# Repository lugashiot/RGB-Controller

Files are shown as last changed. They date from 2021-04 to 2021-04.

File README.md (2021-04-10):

# RGB-Controller
Repository for our selfmade RGB Controller.

We want to use different methods to use the Controller, eg. Blynk or MQTT.
Blynk is done already, but we are still working on MQTT.

Our project is for personal use only, you are not allowed to sell it in any kind.
If you want to build it yourself, check the [Hardware](/Hardware/) directory, all the parts are listed and you can upload the zip folder to order a PCB. 
We purchased the ESP8266 and the 12V PSU via Aliexpress. (The ESP usually has some headers included)
We used https://jlcpcb.com/ for the PCB and https://lcsc.com/ for the parts.

We used code of these repositories:
- https://github.com/tzapu/WiFiManager
- https://github.com/bblanchon/ArduinoJson
- https://github.com/jenscski/DoubleResetDetect
- https://github.com/esp8266/Arduino
- https://blynk.io/

#theoretisch genial, praktisch egal

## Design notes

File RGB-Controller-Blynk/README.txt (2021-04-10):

Final Version:
Über eigenen Wlan Hotspot konfigurieren
 - Authkey ändern
 - Pinkombination ändern (wenn RGB am Lichtstreifen anders angeordnet ist)
DEBUG auskommentieren wenn nicht benötigt
remotecontrol definieren um via http requests variablen zu verändern (zb Farbe, Helligkeit etc.)
RGBSLIDERCODE definieren um eigene RGB Werte am Lichtstreifen auszugeben (Slider müssen in der App extra hinzugefügt werden! Dreifarbige Werte werden am Lichtstreifen sehr weißlich dargestellt)

Um das Wlan zu konfigurieren, 2 mal schnell hintereinander den Reset Knopf drücken.
LED leuchtet jetzt durchgehend.
In der App den Authkey kopieren
mit Wlan "RGB-Controller" verbinden und auf "Im Netzwerk anmelden" klicken.
Jetzt auf "Configure Wifi" klicken,
Wlan Details eingeben
Authkey einfügen
(wenn nötig Pinkombination verändern)
und auf "Save" klicken.

Der RGB Controller ist jetzt fertig eingerichtet.

Virtual Pin Belegung:

V0: 	Menu (1,2,3,4) Farbmodi
V1: 	Delay (1-30) slider
V2: 	manual button (0,1) sliderbutton
V3,4,5: RGB Slider (0-255) 
V7: 	RGB ZEBRA (0-255)
V9: 	brightness slider (1-100)
V10: 	onoff (0,1)

NUR WENN remotecontrol DEFINIERT IST
V30,31,32: 	RGB Remote (0-255)

http://blynk-cloud.com/authkey/update/V(#PIN)?value=(#WERT)
http://blynk-cloud.com/authkey/get/V(#PIN)

Farben stimmen nicht überein? In Web Menü (siehe Wlan konfigurieren) bei "Pin Belegung (optional)" den richtigen Zahlencode für den Lichtstreifen einfügen.

Pin Header  +12V G R B
Colorcode        540      

Pin Header  +12V R G B
Colorcode        450

Pin Header  +12V B G R
Colorcode        054

Pin Header  +12V B R G
Colorcode        045

Pin Header  +12V G B R
Colorcode        504

Pin Header  +12V R B G
Colorcode        405

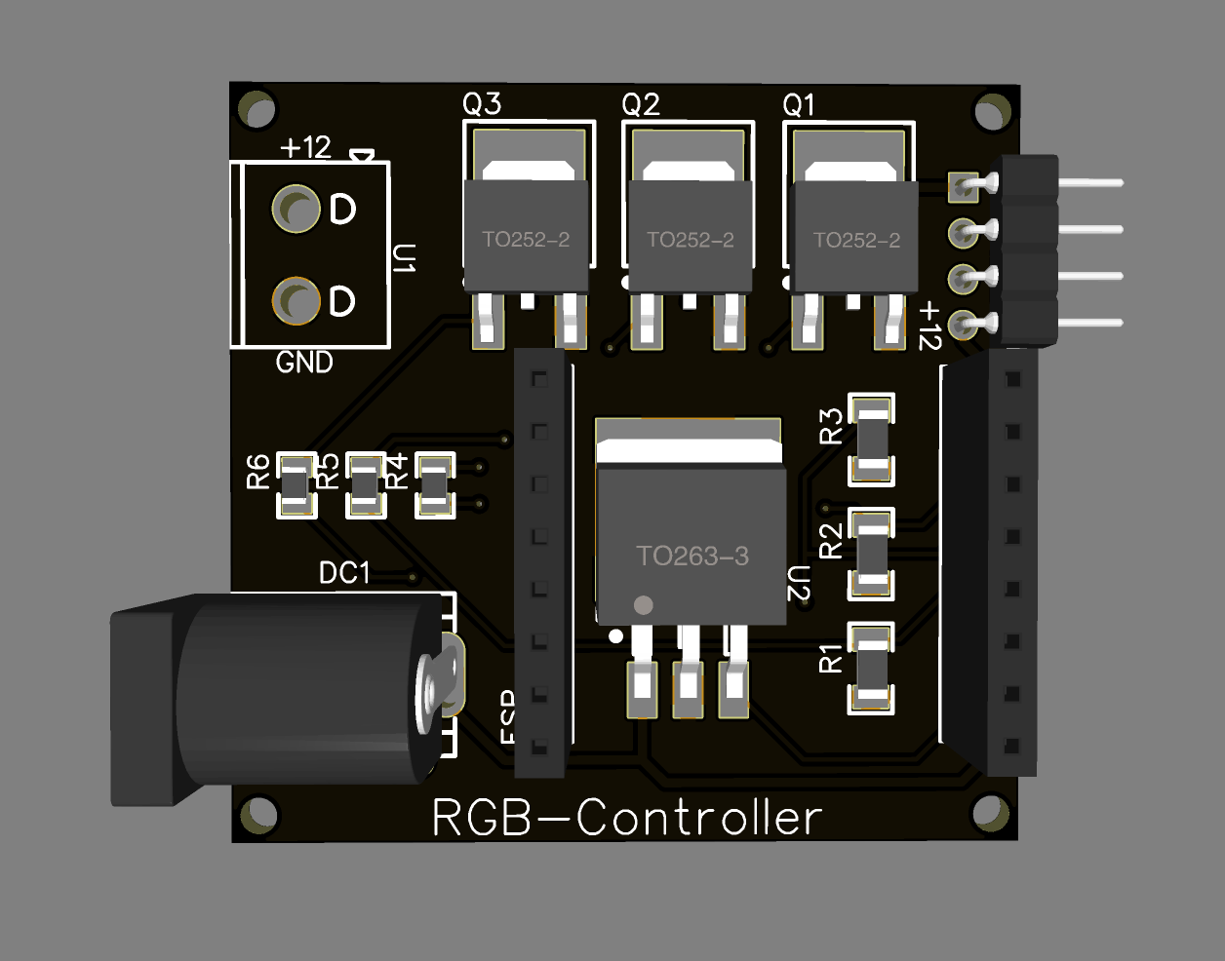
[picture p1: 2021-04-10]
Hardware/PCB/PCB.png

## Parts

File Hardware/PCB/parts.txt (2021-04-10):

Count	Part			Part Number
----------------------------------------------
1	Powerjack		DC005
1	Screw Terminal		JL300-50002U01
1	Header for LED		C88278
1	Voltage Regulator	LM7805S/TR
3	Mosfet			SE30150B
3	R1, R2, R3		TC0625F1002T5E
3	R4, R5, R6		TC0550D5601T5J
1	D1 Mini - ESP8266 (if possible with Male and Female Headers included)
1	12V Powersupply (if not compatible with DC005 use the Screw Terminal)

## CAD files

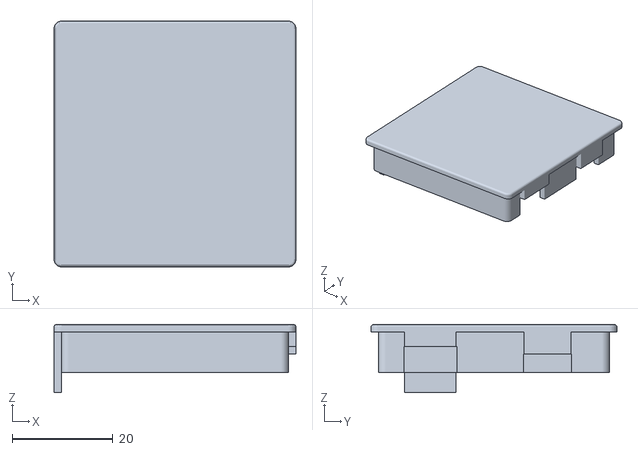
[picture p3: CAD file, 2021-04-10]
Hardware/3D_Print/RGB_Controller_Top.stl
48.0 x 48.8 x 13.5

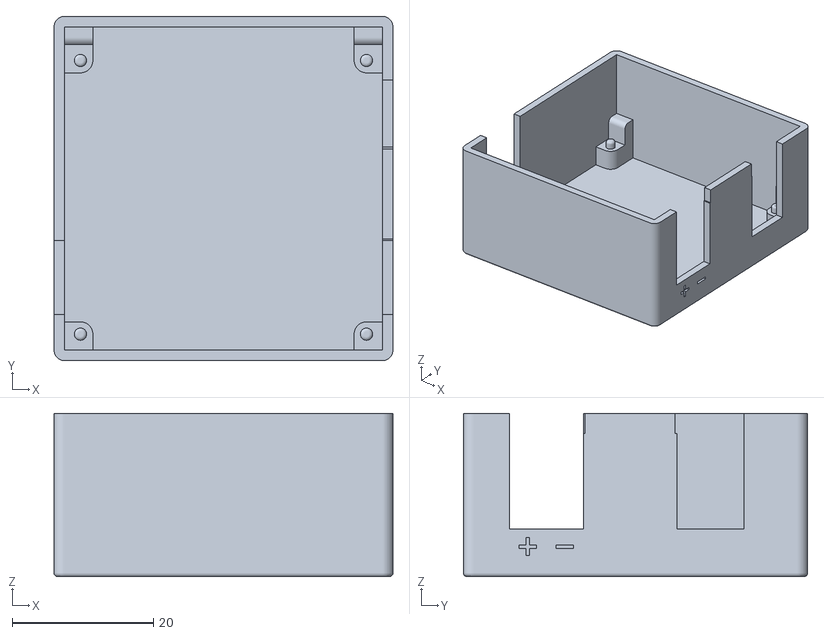
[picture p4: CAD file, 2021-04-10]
Hardware/3D_Print/RGB_Controller_Bottom.stl
48.0 x 48.8 x 23.1

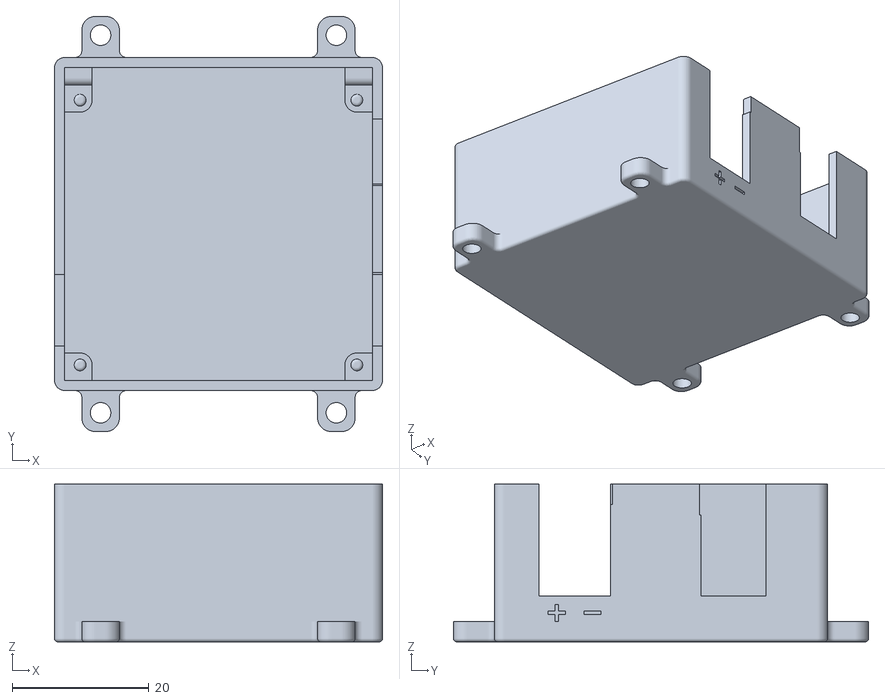
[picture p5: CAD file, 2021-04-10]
Hardware/3D_Print/RGB_Controller_Bottom_Screws.stl
48.0 x 60.8 x 23.1

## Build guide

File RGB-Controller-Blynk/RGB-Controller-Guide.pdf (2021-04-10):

## RGB-Controller Setup Guide

1. First, make sure your LEDs are 12V.
2. Download the Blynk app on Play store or Appstore.

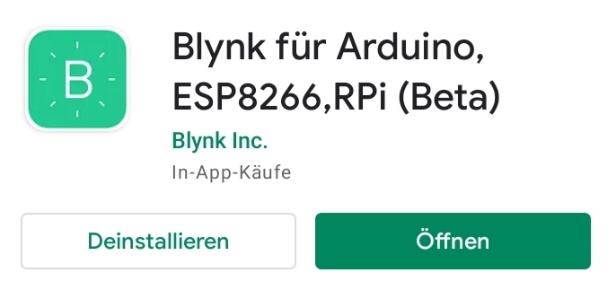
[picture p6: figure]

3. Click the “Scan QR-code” button and scan the QR-code.

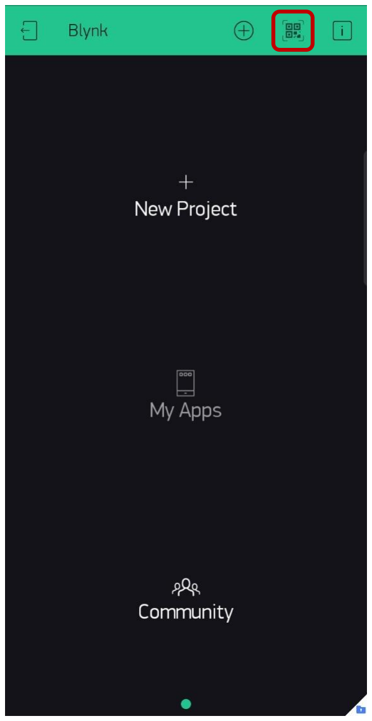
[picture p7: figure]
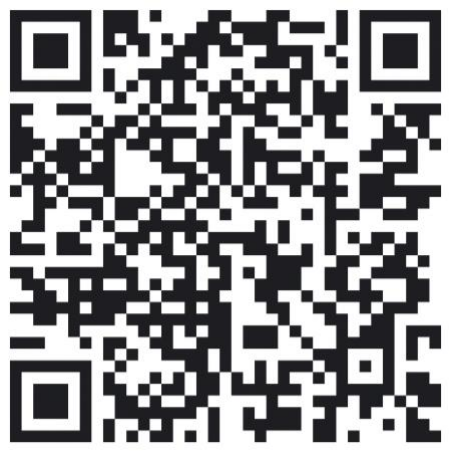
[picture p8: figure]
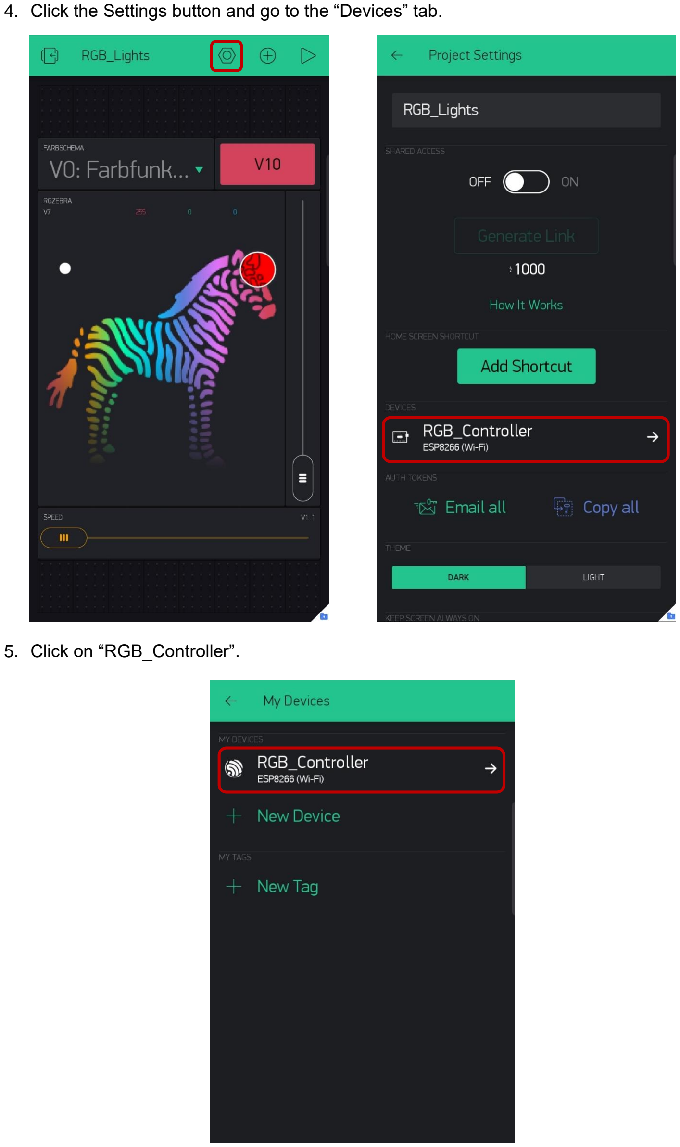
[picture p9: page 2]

4. Click the Settings button and go to the “Devices” tab.
5. Click on “RGB_Controller”.

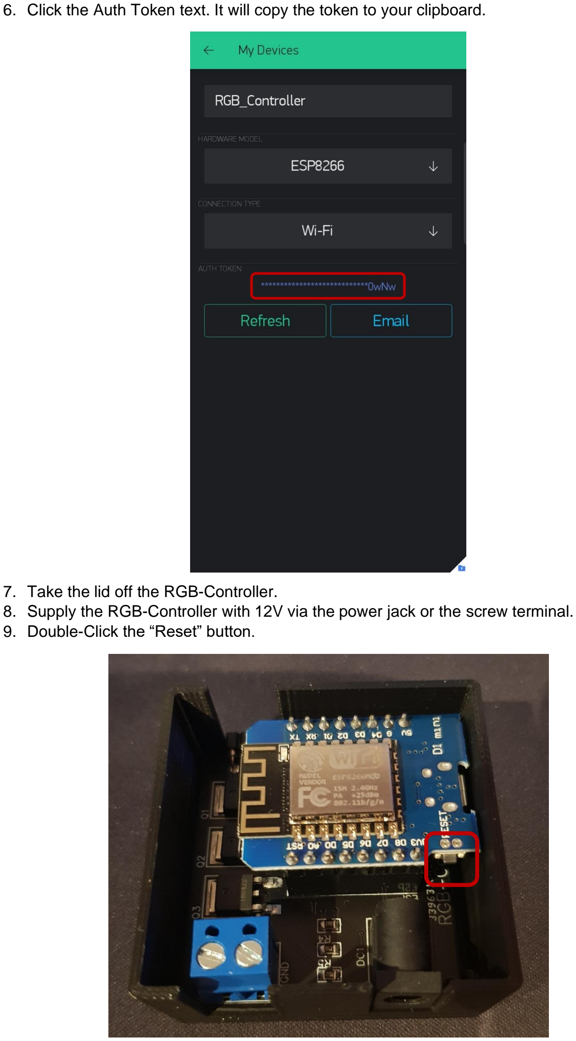
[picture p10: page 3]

6. Click the Auth Token text. It will copy the token to your clipboard.
7. Take the lid off the RGB-Controller.
8. Supply the RGB-Controller with 12V via the power jack or the screw terminal.
9. Double-Click the “Reset” button.

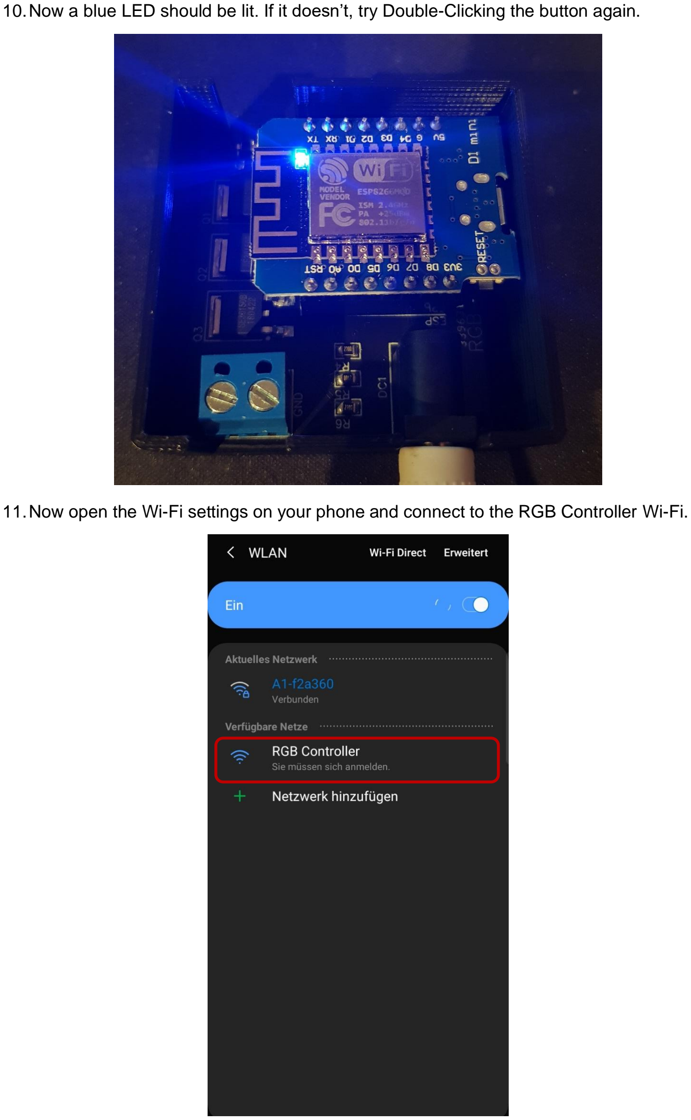
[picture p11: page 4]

10.Now a blue LED should be lit. If it doesn’t, try Double-Clicking the button again.

11.Now open the Wi-Fi settings on your phone and connect to the RGB Controller Wi-Fi.

12. You will be redirected to a login page. Click your Wi-Fi name (1), enter the Password (2), click and hold on the “auth token” field to paste your auth token (3). Then press on the “Save” button (4).

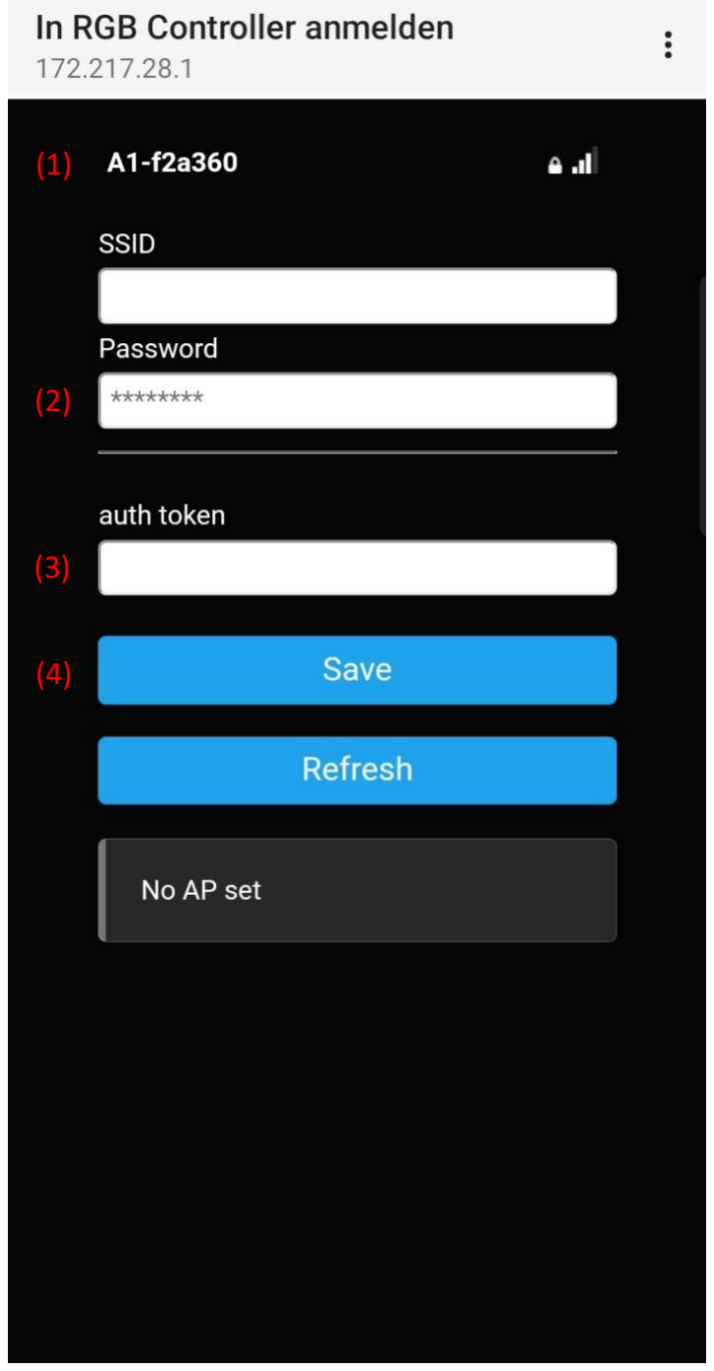
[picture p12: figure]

13.Now you should be automatically reconnected with your Wi-Fi, else you can do it manually.

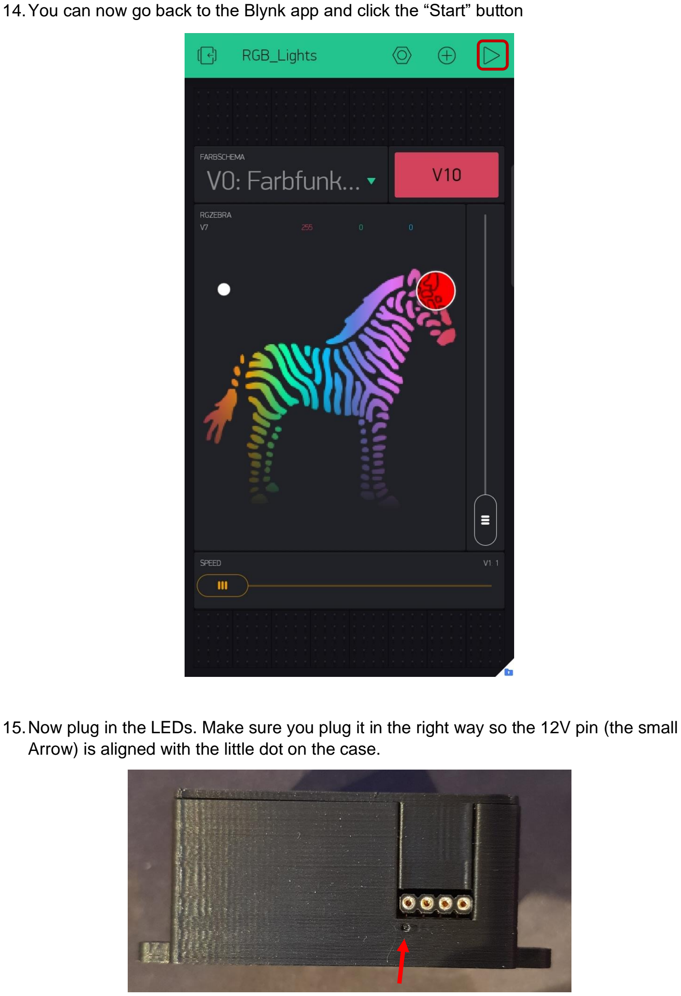
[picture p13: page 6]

14.You can now go back to the Blynk app and click the “Start” button

15.Now plug in the LEDs. Make sure you plug it in the right way so the 12V pin (the small Arrow) is aligned with the little dot on the case.

16. If the colors are wrong, check the order of your RGB-Strip and change the Colorcode (1) in the Wi-Fi Menu.

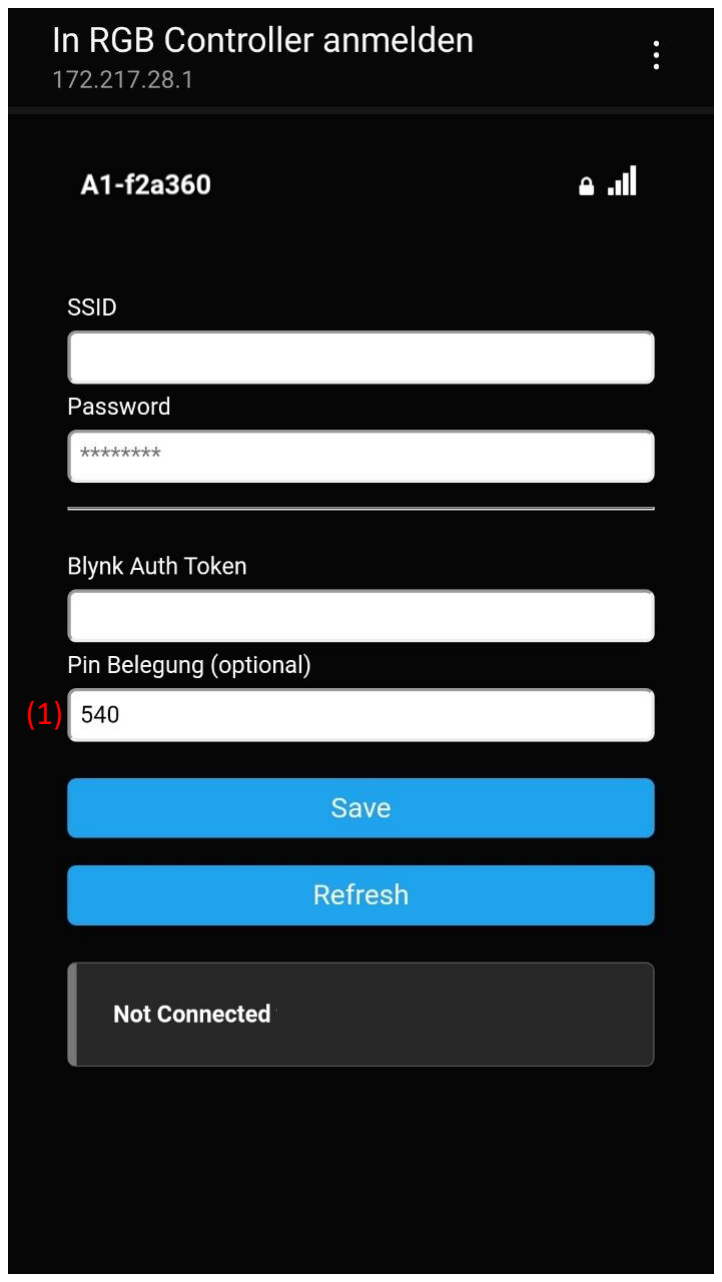
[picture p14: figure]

Pin Header | +12V G R B
Colorcode | 540
Pin Header | +12V R G B
Colorcode | 450
Pin Header | +12V B G R
Colorcode | 054
Pin Header | +12V B R G
Colorcode | 045
Pin Header | +12V G B R
Colorcode | 504
Pin Header | +12V R B G
Colorcode | 405

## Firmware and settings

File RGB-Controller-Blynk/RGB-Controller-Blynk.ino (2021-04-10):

//#define RGBSLIDERCODE
//#define DEBUG
#define remotecontrol

//theoretisch genial, praktisch egal

#define BLYNK_PRINT Serial
#include <ESP8266WiFi.h>
#include <BlynkSimpleEsp8266.h>

#include <FS.h>          // this needs to be first, or it all crashes and burns...
#include <WiFiManager.h> // https://github.com/tzapu/WiFiManager
#include <ArduinoJson.h> // https://github.com/bblanchon/ArduinoJson

#include <DoubleResetDetect.h>

#define DRD_TIMEOUT 2.0
#define DRD_ADDRESS 0x00

DoubleResetDetect drd(DRD_TIMEOUT, DRD_ADDRESS);
WiFiManager wifiManager;

//define your default values here, if there are different values in config.json, they are overwritten.
char api_token[33];
char rgb_changed[] = "540";     //Colorcode, check README.txt for the Codes, it is changeable via the WiFi configuration
char ssid[40];
char pass[40];

//flag for saving data
bool shouldSaveConfig = false;

int menu_pin = 0;
int user_delay = 30;
int rainbow_state = 0;
int brightness = 100;
int manual_pin_state = 0;
int onoff = 1;

// R G B values used for the Output, 0...1023
int R = 0;
int G = 0;
int B = 0;

#ifdef RGBSLIDERCODE 
int r_slider;
int g_slider;
int b_slider;
#endif

//declaration of the Outputpins
/*
#define R_LED D1
#define G_LED D2
#define B_LED D3
*/
uint8_t R_LED;
uint8_t G_LED;
uint8_t B_LED;


//deafault delay values for the colorfunctions
#define epilepsy_start 40
#define rainbow_start 50
#define breathing_start 25

void push(int bright_temp = brightness) {
  analogWrite(R_LED, R * bright_temp / 100 * onoff);
  analogWrite(G_LED, G * bright_temp / 100 * onoff);
  analogWrite(B_LED, B * bright_temp / 100 * onoff);
  Blynk.run();
#ifdef DEBUG
  Serial.printf("\nRGB-Values: %d %d %d | %d % Brightness | %d ONOFF", R, G, B, bright_temp, onoff);
#endif
}

//read menu pin
BLYNK_WRITE(V0) {
  menu_pin = param.asInt();
#ifdef DEBUG
  Serial.println("Colorfunction has been changed in the menu.");
#endif
  manual_pin_state = 0;
  Blynk.virtualWrite(V2, LOW);
  if (menu_pin == 1) {
    // use default delay 
    Blynk.virtualWrite(V1, epilepsy_start);
    user_delay = epilepsy_start;
    user_delay = map(user_delay, 1, 100, 40, 1);
  }
  else if (menu_pin == 2) {
    // use default delay 
    Blynk.virtualWrite(V1, rainbow_start);
    user_delay = rainbow_start;
    user_delay = map(user_delay, 1, 100, 40, 1);
  }
  else if (menu_pin == 3) {
    // use default delay 
    Blynk.virtualWrite(V1, breathing_start);
    user_delay = breathing_start;
    user_delay = map(user_delay, 1, 100, 40, 1);
  }
}

//read user delay
BLYNK_WRITE(V1) {
  user_delay = param.asInt();
  user_delay = map(user_delay, 1, 100, 40, 1);
#ifdef DEBUG
  Serial.println("Delay/Speed has been changed.\n");
#endif
}

#ifdef RGBSLIDERCODE   
// codepart used for custom RGB Sliders in the Blynk app
// Button V2
// Set the Sliders on a range of 0 to 255
// RED: V3    GREEN: V4      BLUE: V5
// "send on release" is our recommendation

//read manual pin
BLYNK_WRITE(V2) {
  manual_pin_state = param.asInt();
  menu_pin = 0;
#ifdef DEBUG
  Serial.println("Slider Button has been pressed.");
#endif
}

//red slider
BLYNK_WRITE(V3) {
  r_slider = param.asInt() * 4;
#ifdef DEBUG
  Serial.println("Red Slider has been moved.");
#endif
}

//green slider
BLYNK_WRITE(V4) {
  g_slider = param.asInt() * 4;
#ifdef DEBUG
  Serial.println("Green Slider has been moved.");
#endif
}

//blue slider
BLYNK_WRITE(V5) {
  b_slider = param.asInt() * 4;
#ifdef DEBUG
  Serial.println("Blue Slider has been moved.");
#endif
}
#endif

//rgb zebra output to leds
BLYNK_WRITE(V7) {
  R = param[0].asInt() * 4;
  G = param[1].asInt() * 4;
  B = param[2].asInt() * 4;
  menu_pin = 0;
#ifdef RGBSLIDERCODE
  manual_pin_state = 0;
#endif
  Blynk.virtualWrite(V2, LOW);
  push();
#ifdef DEBUG
  Serial.println("Zebra RGB color has been changed.");
#endif
}

//brightness slider
BLYNK_WRITE(V9) {
  brightness = param.asInt();
#ifdef DEBUG
  Serial.println("Brightness has been changed.");
#endif
}

//on-off switch
BLYNK_WRITE(V10) {
  onoff = param.asInt();
#ifdef DEBUG
  Serial.printf("\nLeds are now %d", onoff);
#endif
}


#ifdef remotecontrol

//remote red
BLYNK_WRITE(V30) {
  menu_pin = 0;
  Blynk.virtualWrite(V10, HIGH);
  onoff = 1;
  R = param.asInt() * 4;
#ifdef RGBSLIDERCODE
  manual_pin_state = 0;
  Blynk.virtualWrite(V2, LOW);
#endif
#ifdef DEBUG
  Serial.println("Color has been remotely changed.");
#endif
}

//remote green
BLYNK_WRITE(V31) {
  menu_pin = 0;
  Blynk.virtualWrite(V10, HIGH);
  onoff = 1;
  G = param.asInt() * 4;
#ifdef RGBSLIDERCODE
  manual_pin_state = 0;
  Blynk.virtualWrite(V2, LOW);
#endif
#ifdef DEBUG
  Serial.println("Color has been remotely changed.");
#endif
}

//remote blue
BLYNK_WRITE(V32) {
  menu_pin = 0;
  Blynk.virtualWrite(V10, HIGH);
  onoff = 1;
  B = param.asInt() * 4;
#ifdef RGBSLIDERCODE
  manual_pin_state = 0;
  Blynk.virtualWrite(V2, LOW);
#endif
#ifdef DEBUG
  Serial.println("Color has been remotely changed.");
#endif
}

#endif


void setupSpiffs() {
  //clean FS, for testing
  // SPIFFS.format();

  //read configuration from FS json
#ifdef DEBUG
  Serial.println("mounting FS...");
#endif
  if (SPIFFS.begin()) {
#ifdef DEBUG
    Serial.println("mounted file system");
#endif
    if (SPIFFS.exists("/config1.json")) {
      //file exists, reading and loading
#ifdef DEBUG
      Serial.println("reading config file");
#endif
      File configFile = SPIFFS.open("/config1.json", "r");
      if (configFile) {
#ifdef DEBUG
        Serial.println("opened config file");
#endif
        size_t size = configFile.size();
        // Allocate a buffer to store contents of the file.
        std::unique_ptr<char[]> buf(new char[size]);

        configFile.readBytes(buf.get(), size);
        DynamicJsonBuffer jsonBuffer;
        JsonObject& json = jsonBuffer.parseObject(buf.get());
        json.printTo(Serial);
        if (json.success()) {
#ifdef DEBUG
          Serial.println("\nparsed json");
#endif
          strcpy(api_token, json["api_token"]);
          strcpy(rgb_changed, json["pins"]);
          char *p1 = &rgb_changed[0];
          char *p2 = &rgb_changed[1];
          char *p3 = &rgb_changed[2];
          R_LED = (uint8_t)atoi(p1);
          G_LED = (uint8_t)atoi(p2);
          B_LED = (uint8_t)atoi(p3);
        }
        else {
#ifdef DEBUG
          Serial.println("failed to load json config");
#endif
        }
      }
    }
  } else {
#ifdef DEBUG
    Serial.println("failed to mount FS");
#endif
  }
  //end read
}

//callback notifying us of the need to save config
void saveConfigCallback () {
#ifdef DEBUG
  Serial.println("Should save config");
#endif
  shouldSaveConfig = true;
}

// check, if some values have changed while a colorfunction is running
bool rainbow_change (float speedo) {
  if (menu_pin != 2 or manual_pin_state != 0 or speedo != (user_delay)) {
    return true;
  }
}

bool breathing_change (float speedo) {
  if (menu_pin != 3 or manual_pin_state != 0 or speedo != user_delay) {
    return true;
  }
}

bool epilepsy_change (float del) {
  if (menu_pin != 1 or manual_pin_state != 0 or del != user_delay) {
    return true;
  }
}

//Colorfunction Police
int police() {

  //red
  R = 1023; G = 0; B = 0;
  push();
  delay(150);

  R = 0; G = 0; B = 0;
  push();
  delay(40);

  R = 1023; G = 0; B = 0;
  push();
  delay(100);

  R = 0; G = 0; B = 0;
  push();
  delay(40);

  R = 1023; G = 0; B = 0;
  push();
  delay(200);

  R = 0; G = 0; B = 0;
  push();
  delay(40);

  if (menu_pin != 4 or manual_pin_state == 1) {
    return 0;
  }

  // blue
  R = 0; G = 0; B = 1023;
  push();
  delay(150);

  R = 0; G = 0; B = 0;
  push();
  delay(40);

  R = 0; G = 0; B = 1023;
  push();
  delay(100);

  R = 0; G = 0; B = 0;
  push();
  delay(40);

  R = 0; G = 0; B = 1023;
  push();
  delay(200);

  R = 0; G = 0; B = 0;
  push();
  delay(40);

  return 0;
}

//Colorfunction Regenbogen
int rainbow(int speedo) {
  if (rainbow_state == 0) {
    R = 1023; G = 0; B = 0;
    for (int i = 0; i < 1023; i += 3) {
      G += 3;
      push();
      if (rainbow_change(speedo)) {
        return 0;
      }
      delay(speedo);
    }
    rainbow_state = 1;
  }
  else if (rainbow_state == 1) {
    R = 1023; G = 1023; B = 0;
    for (int i = 1023; i > 0; i -= 3) {
      R -= 3;
      push();
      if (rainbow_change(speedo)) {
        return 0;
      }
      delay(speedo);
    }
    rainbow_state = 2;
  }
  else if (rainbow_state == 2) {
    R = 0; G = 1023; B = 0;
    for (int i = 0; i < 1023; i += 3) {
      B += 3;
      push();
      if (rainbow_change(speedo)) {
        return 0;
      }
      delay(speedo);
    }
    rainbow_state = 3;
  }
  else if (rainbow_state == 3) {
    R = 0; G = 1023; B = 1023;
    for (int i = 1023; i > 0; i -= 3) {
      G -= 3;
      push();
      if (rainbow_change(speedo)) {
        return 0;
      }
      delay(speedo);
    }
    rainbow_state = 4;
  }
  else if (rainbow_state == 4) {
    R = 0; G = 0; B = 1023;
    for (int i = 0; i < 1023; i += 3) {
      R += 3;
      push();
      if (rainbow_change(speedo)) {
        return 0;
      }
      delay(speedo);
    }
    rainbow_state = 5;
  }
  else if (rainbow_state == 5) {
    R = 1023; G = 0; B = 1023;
    for (int i = 1023; i > 0; i -= 3) {
      B -= 3;
      push();
      if (rainbow_change(speedo)) {
        return 0;
      }
      delay(speedo);
    }
    rainbow_state = 0;
  }
  return 0;
}

//Colorfunction Atmung
int breathing(int speedo)
{
  brightness = 100;
  push();

  //downwards
  while (brightness >= 0) {
    brightness--;
    push();
    if (breathing_change(speedo)) {
      return 0;
    }
    delay(speedo);
  }

  //black
  push();
  delay(speedo * 15);

  //upwards
  while (brightness <= 100) {
    brightness++;
    push();
    if (breathing_change(speedo)) {
      return 0;
    }
    delay(speedo);
  }

  //on
  delay(speedo * 15);
}

//Colorfunction epilepsy
int epilepsy(int del)
{
  //white
  R = 1023; G = 1023; B = 1023;
  push();
  delay(del);

  R = 0; G = 0; B = 0;
  push();
  delay(del);

  if (epilepsy_change(del)) {
    return 0;
  }

  //red
  R = 1023; G = 0; B = 0;
  push();
  delay(del);

  R = 0; G = 0; B = 0;
  push();
  delay(del);

  if (epilepsy_change(del)) {
    return 0;
  }

  //green
  R = 0; G = 1023; B = 0;
  push();
  delay(del);

  R = 0; G = 0; B = 0;
  push();
  delay(del);

  if (epilepsy_change(del)) {
    return 0;
  }

  //blue
  R = 0; G = 0; B = 1023;
  push();
  delay(del);

  R = 0; G = 0; B = 0;
  push();
  delay(del);

  if (epilepsy_change(del)) {
    return 0;
  }
  return 0;
}

void setup() {
#ifdef DEBUG
  Serial.begin(9600);
#endif

  //turn the RGB Strip white on startup
  R = 1023; G = 1023; B = 1023;
  brightness = 100;
  user_delay = 10;
  push();

  WiFiManager wm;
  pinMode(D4, OUTPUT);
  
  if (drd.detect()) {
#ifdef DEBUG
    Serial.println("Entered Wifi setup");
#endif
    digitalWrite(D4, LOW); //turns bultin led on

    setupSpiffs();

    //set config save notify callback
    wm.setSaveConfigCallback(saveConfigCallback);

    // setup custom parameters
    WiFiManagerParameter custom_api_token("api", "Blynk Auth Token", "", 33);
    WiFiManagerParameter rgb_change_values("rgbpins", "Pin Order/Colorcode (optional)", rgb_changed, 4);

    //add all your parameters here
    wm.addParameter(&custom_api_token);
    wm.addParameter(&rgb_change_values);

    // start configportal for a little 300 seconds
    wm.setConfigPortalTimeout(300);
    wm.setClass("invert");

    //set custom ip for portal
    wm.setAPStaticIPConfig(IPAddress(172, 217, 28, 1), IPAddress(172, 217, 28, 1), IPAddress(255, 255, 255, 0));

    // start portal
    wm.startConfigPortal("RGB Controller");

    //if you get here you have connected to the WiFi
#ifdef DEBUG
    Serial.println("connected...yeey :)");
#endif
    //read updated parameters
    strcpy(api_token, custom_api_token.getValue());
    strcpy(rgb_changed, rgb_change_values.getValue());
    
    int ssid_str_len = wm.getWiFiSSID().length() + 1;
    char ssid_char_array[ssid_str_len];
    wm.getWiFiSSID().toCharArray(ssid_char_array, ssid_str_len);

    int pass_str_len = wm.getWiFiPass().length() + 1;
    char pass_char_array[pass_str_len];
    wm.getWiFiPass().toCharArray(pass_char_array, pass_str_len);

    strcpy(ssid, ssid_char_array);
    strcpy(pass, pass_char_array);

    //save the custom parameters to FS
    if (shouldSaveConfig) {
#ifdef DEBUG
      Serial.println("saving config");
#endif

      char *p1 = &rgb_changed[0];
      char *p2 = &rgb_changed[1];
      char *p3 = &rgb_changed[2];
      R_LED = (uint8_t)atoi(p1);
      G_LED = (uint8_t)atoi(p2);
      B_LED = (uint8_t)atoi(p3);
     
      DynamicJsonBuffer jsonBuffer;
      JsonObject& json = jsonBuffer.createObject();
      json["api_token"]   = api_token;
      json["ssid"]        = ssid;
      json["pass"]        = pass;
      json["pins"]        = rgb_changed;
      
      // json["ip"]          = WiFi.localIP().toString();
      // json["gateway"]     = WiFi.gatewayIP().toString();
      // json["subnet"]      = WiFi.subnetMask().toString();

      File configFile = SPIFFS.open("/config1.json", "w");
#ifdef DEBUG
      if (!configFile) {
        Serial.println("failed to open config file for writing");
      }
#endif
      json.prettyPrintTo(Serial);
      json.printTo(configFile);
      configFile.close();
      //end save
      shouldSaveConfig = false;
    }
#ifdef DEBUG
    Serial.println("\nlocal ip");
    Serial.println(WiFi.localIP());
    Serial.println(WiFi.gatewayIP());
    Serial.println(WiFi.subnetMask());

    Serial.print("SSID: ");
    Serial.println(ssid);
    Serial.print("PW: ");
    Serial.println(pass);
    Serial.print("auth: ");
    Serial.println(api_token);
#endif
    wm.stopConfigPortal();
    digitalWrite(D4, HIGH); //turns bultin led off
  } else {
#ifdef DEBUG
    Serial.println("Using existing Wifi");
#endif
    setupSpiffs();
    digitalWrite(D4, HIGH); //turns bultin led off
  }

  Blynk.begin(api_token, ssid, pass);
  Blynk.virtualWrite(V1, 10);
  Blynk.virtualWrite(V7, 255);
  Blynk.virtualWrite(V9, 100);
  Blynk.virtualWrite(V10, 1);
  pinMode(R_LED, OUTPUT);
  pinMode(G_LED, OUTPUT);
  pinMode(B_LED, OUTPUT);
  
#ifdef RGBSLIDERCODE
  Blynk.virtualWrite(V2, LOW);
  Blynk.virtualWrite(V3, 0);
  Blynk.virtualWrite(V4, 0);
  Blynk.virtualWrite(V5, 0);
#endif
}

void loop() {
  if (manual_pin_state == 0) {
    if (menu_pin == 1) {
      epilepsy(user_delay);
    }
    else if (menu_pin == 2) {
      rainbow(user_delay);
    }
    else if (menu_pin == 3) {
      breathing(user_delay);
    }
    else if (menu_pin == 4) {
      police();
    }
  }

#ifdef RGBSLIDERCODE
  else if (manual_pin_state == 1)
  {
    R = r_slider;
    G = g_slider;
    B = b_slider;
  }
#endif
  push();
}
